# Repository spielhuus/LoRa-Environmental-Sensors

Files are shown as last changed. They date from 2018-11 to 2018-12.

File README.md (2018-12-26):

# LoRa Environmental Sensors 

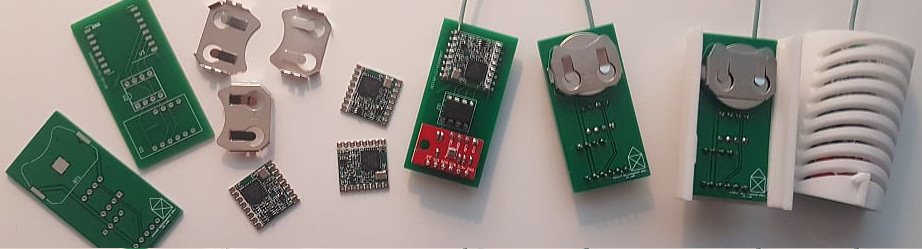
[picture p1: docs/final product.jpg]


Arduino based board for a Atmospheric Sensor BME280 LoRaWan Node. The LoRa Node measures barometric pressure, humidity, and temperature every 5 min. After the measurements, the ATtiny85 goes into sleep mode and is awakened by the watchdog timer. The RFM module sends the values to the TTN backend with Activation by Personalization (ABP) a fixed spreading factor and one of the four random channels. This project is based on the TinyLoRa-BME280 project [1].

## BOM

|Ref|Value|Description|
| --- | --- | --- |
|BT1| [3034](https://spielhuus.github.io/LoRa-Environmental-Sensors/3034.pdf) |Battery Cell Holder|3034 1x20mm](https://www.keyelco.com/product.cfm/product_id/798)| 
|BT1| CR2032 |Battery Cell CR2032 (210 – 230 mAh)| 
|U1| [BME280](https://spielhuus.github.io/LoRa-Environmental-Sensors/BST-BME280_DS001-10.pdf) | [SparkFun BME280](https://github.com/sparkfun/SparkFun_BME280_Breakout_Board)|
|U2| [ATtiny85-20SU](https://spielhuus.github.io/LoRa-Environmental-Sensors/atmel-2586-avr-8-bit-microcontroller-attiny25-attiny45-attiny85_datasheet.pdf) | Atmel 8-bit AVR Microcontroller|
|U3| [RFM95W-868S2](https://spielhuus.github.io/LoRa-Environmental-Sensors/RFM95_96_97_98W.pdf) | Low Power Long Range Transceiver Module |
| - | Wire | Wire for the antenna, 8.6 cm |

The ATmega microprocessor needs an arduino bootloader. To burn a bootloader to the blank chip see [2]

## Wiring

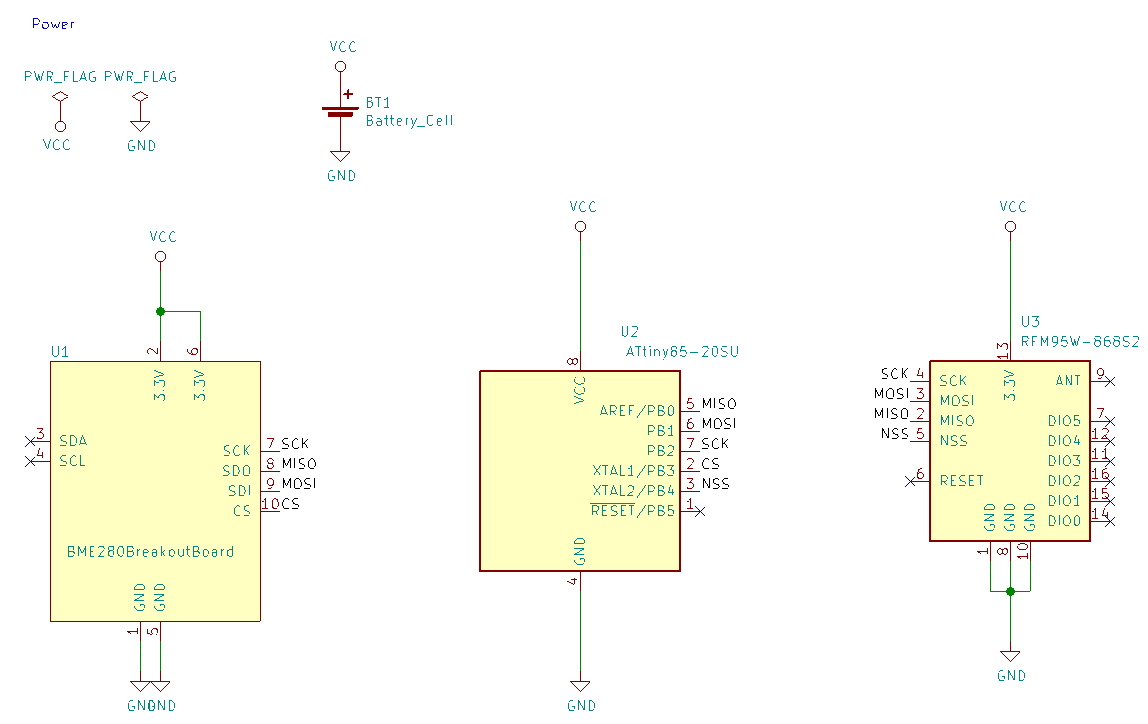
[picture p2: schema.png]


| ATtiny85 | RFM95 | BME280 |
| --- | ----- | --- |
| PB3 | | CS (Slave Select) |
| PB4 | NSS (Slave Select) | |
| PB2 | SCK | SCK |
| PB1(DO) | MOSI | SDI |
| PB0(DI) | MISO | SDO |

## Installation

The Arduino IDE has to be properly installed. 

Add the Libraries to you IDE:

- Install the Attiny Baord Manager
  - Under Preferences > Additional Boards Manager URLs: https://raw.githubusercontent.com/damellis/attiny/ide-1.6.x-boards-manager/package_damellis_attiny_index.json

  Multiple managers can be separated with a comma.

- Install TinyLoRa-BME280 v1.1
  - Download the ZIP archive from [TinyLoRa-BME280 v1.1](https://github.com/ClemensRiederer/TinyLoRa-BME280_v1.1)
  - Install the ZIP archive in the Arduino Library Manager

- Open Examples > TinyLoRa-BME280_v1.1-master > ATtiny_LoRa_BME280
  - Edit NwkSkey, AppSkey, DevAddr
  - Change the Spreading Factor in ATtinyLoRa.cpp
  - The Sleep time can be set with the SLEEP_TOTAL var.

- Burn the sketch to the Chip using an Arduino UNO [2]
  - Burn a bootloader first to set the fuses correctly

## Payload Format

The Payload is encoded as byte array.

| byte | content |
| ---- | --- |
| 0..1 | temperature (*100) |
| 2..3 | humidity (*100) |
| 4..8 | barometric pressure |

To decode the values add this code in the TTM Console as decoder under Paload Formats.

```
function Decoder(bytes, port) {
  temp = ((bytes[0]) << 8)
              + ((bytes[1]));
  hum = ((bytes[2]) << 8)
              + ((bytes[3]));
  pres = ((bytes[4]) << 24)
              + ((bytes[5]) << 16)
              + ((bytes[6]) << 8)
              + ((bytes[7]));

  return {
    pressure: ( pres / 100 ),
    temperature: ( temp / 100 ),
    humidity: ( hum / 100 )
  };
}
```

## Links

1. [TinyLoRa-BME280 v1.1](https://github.com/ClemensRiederer/TinyLoRa-BME280_v1.1)
2. [Programming ATtiny85 with Arduino Uno](https://www.hackster.io/arjun/programming-attiny85-with-arduino-uno-afb829)

## License

[License CC BY 4.0](http://creativecommons.org/licenses/by/4.0/) - Attribution 4.0 International

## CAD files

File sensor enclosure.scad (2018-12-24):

// Enclosure for the LoRA environmental sensor.

l=52;
w=27;
th=5;
h=12;

board_w=25;
board_l=50;
board_h=2;

lidText = "2";  // Text on lid    
lidTextSize = 20;   // Size of text on Lid
lidTextFont = "Droid Sans:style=Bold";  // Font for lid text

// the text
translate([0,-l/2+5,-th-w/2+1])
    rotate(0) linear_extrude(height = 3)
        mirror([1,0,0]) 
            text(lidText, font = lidTextFont, size = lidTextsize, valign = "center", halign = "center");

//the slider for the pcb
difference() {
    translate([-w/2,-l/2,-h/2+board_h-1]) cube([board_w+3,board_l,board_h+2] );
    translate([0,th/2,-h/2+3]) cube([board_w+1,board_l+2*th,board_h], center=true);
    translate([0,th/2,-h/2+3]) cube([board_w-2,board_l+2*th,board_h+2], center=true);
}


translate([-w/2-th/4,0,-h/2+3+th]) cube([th/2,l,th], center=true);
translate([+w/2+th/4,0,-h/2+3+th]) cube([th/2,l,th], center=true);

translate([0,0,0]) {
    difference() {
        rotate(a=[0,270,90]) cylinder(h=l,d=w+th,center=true,$fn=100);
        rotate(a=[0,270,90]) cylinder(h=l+th,d=w,center=true,$fn=100);
        translate([0,0,h]) cube([w*2,l,h*2], center=true);

        //vents
        translate([0, -10,-w]) rotate([120,0,0]) cube([w*2,l,2], center=true);
        translate([0, -5,-w]) rotate([120,0,0]) cube([w*2,l,2], center=true);
        translate([0, 0,-w]) rotate([120,0,0]) cube([w*2,l,2], center=true);
        translate([0, 5,-w]) rotate([120,0,0]) cube([w*2,l,2], center=true);
        translate([0, 10,-w]) rotate([120,0,0]) cube([w*2,l,2], center=true);
        translate([0, 15,-w]) rotate([120,0,0]) cube([w*2,l,2], center=true);
        translate([0, 20,-w]) rotate([120,0,0]) cube([w*2,l,2], center=true);
        translate([0, 25,-w]) rotate([120,0,0]) cube([w*2,l,2], center=true);
        translate([0, 30,-w]) rotate([120,0,0]) cube([w*2,l,2], center=true);
    }
}

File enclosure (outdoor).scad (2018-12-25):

// Which one would you like to see?
part = "both"; // [box:Box only, top: Top cover only, both: Box and top cover]

// Size of your printer's nozzle in mm
nozzle_size = 0.4;

// Number of walls the print should have
number_of_walls = 2; // [1:5]

// Tolerance (use 0.2 for FDM)
tolerance = 0.2; // [0.1:0.1:0.4]

// Outer x dimension in mm
x=52+2*number_of_walls*nozzle_size+2*3*nozzle_size;

// Outer y dimension in mm
y=27+2*number_of_walls*nozzle_size+2*3*nozzle_size;

// Outer z dimension in mm
z=13+2*number_of_walls*nozzle_size+2*3*nozzle_size;

// Radius for rounded corners in mm
radius=4; // [1:20]

lidText = "7";  // Text on lid    
lidTextSize = 10;   // Size of text on Lid
lidTextFont = "Droid Sans:style=Bold";  // Font for lid text

/* Hidden */
$fn=100;

wall_thickness=nozzle_size*number_of_walls;
hook_thickness = 3*nozzle_size;

top_cover_wall_thickness = hook_thickness + wall_thickness;

module bottom_box () {
    difference(){
        // Solid box
        linear_extrude(z-wall_thickness){
            minkowski(){
                square([x-radius*2,y-radius*2], center=true);
                circle(radius, center=true);
            }
        }
        
        // Hollow out
        translate([0,0,wall_thickness]) linear_extrude(z){
            minkowski(){
                square([x-radius*2-wall_thickness*2+wall_thickness*2,y-radius*2-wall_thickness*2+wall_thickness*2], center=true);
                circle(radius-wall_thickness);
            }
        }
        
            //hole for antenna and vents
        translate([-x/2+3, 7, 2+3]) rotate(a=[0,270,0]) cylinder(h=20, d=2, $fn=100);
        translate([+x/4, -0, 1]) rotate(a=[0,0,90]) cube(size = [2,20,10], center = true);
        translate([+x/4, -4, 1]) rotate(a=[0,0,90]) cube(size = [2,20,10], center = true);
        translate([+x/4, -8, 1]) rotate(a=[0,0,90]) cube(size = [2,20,10], center = true);
        translate([+x/4, +4, 1]) rotate(a=[0,0,90]) cube(size = [2,20,10], center = true);
        translate([+x/4, +8, 1]) rotate(a=[0,0,90]) cube(size = [2,20,10], center = true);

        // the text
        translate([-10,-0,-2-2/2+1])
            rotate(270) linear_extrude(height = 3)
                mirror([1,0,0]) 
        text(lidText, font = lidTextFont, size = lidTextSize, valign = "center", halign = "center");
    }

    left_hook(); // left hook
    rotate([180,180,0]) left_hook(); // right hook
    front_hook(); // front hook
    rotate([180,180,0]) front_hook(); // back hook
    // TODO: hooks on the other two sides
}

module left_hook () {
    
    translate([(x-2*wall_thickness)/2,-y/2+radius*2,z-wall_thickness]) rotate([0,90,90]) {
        difference(){
            linear_extrude(y-2*radius*2){
    polygon(points=[[0,0],[2*hook_thickness,0],[hook_thickness,hook_thickness]], center=true);
        }
             translate([hook_thickness, hook_thickness, 0]) rotate([45,0,0]) cube(2*hook_thickness, center=true);
             translate([hook_thickness, hook_thickness, y-2*radius*2]) rotate([45,0,0]) cube(2*hook_thickness, center=true);        
        }
    }
}
    

module front_hook () {
    translate([(-x+4*radius)/2,-y/2+wall_thickness,z-wall_thickness]) rotate([90,90,90]) {
        difference(){
        linear_extrude(x-2*radius*2){
    polygon(points=[[0,0],[2*hook_thickness,0],[hook_thickness,hook_thickness]], center=true);
    }
             translate([hook_thickness, hook_thickness, 0]) rotate([45,0,0]) cube(2*hook_thickness, center=true);
             translate([hook_thickness, hook_thickness, x-2*radius*2]) rotate([45,0,0]) cube(2*hook_thickness, center=true);
        }
    }
}


module right_grove () {
    translate([-tolerance/2+(x-2*wall_thickness)/2,-y/2+radius,wall_thickness+hook_thickness*2]) rotate([0,90,90]) linear_extrude(y-2*radius){
    polygon(points=[[0,0],[2*hook_thickness,0],[hook_thickness,hook_thickness]], center=true);
    }
}


module front_grove () {
    translate([(-x+2*radius)/2,-y/2+wall_thickness+tolerance/2,wall_thickness+hook_thickness*2]) rotate([90,90,90]) linear_extrude(x-2*radius){
    polygon(points=[[0,0],[2*hook_thickness,0],[hook_thickness,hook_thickness]], center=true);
    }
}

module top_cover () {

    // Top face
    linear_extrude(wall_thickness){
        minkowski(){
            square([x-radius*2,y-radius*2], center=true);
            circle(radius, center=true);
        }
    }
    
    difference(){
        // Wall of top cover
        linear_extrude(wall_thickness+hook_thickness*2){
            minkowski(){
                square([x-radius*2-wall_thickness*2-tolerance+wall_thickness*2,y-radius*2-wall_thickness*2-tolerance+wall_thickness*2], center=true);
                circle(radius-wall_thickness, center=true);
            }
        }
        
        // Hollow out
        // TODO: If radius is very small, still hollow out

        translate([0,0,wall_thickness]) linear_extrude(z){
            minkowski(){
                square([x-radius*2-wall_thickness*2-2*top_cover_wall_thickness-tolerance+wall_thickness*2+top_cover_wall_thickness*2,y-radius*2-wall_thickness*2-2*top_cover_wall_thickness-tolerance+wall_thickness*2+top_cover_wall_thickness*2], center=true);
            circle(radius-wall_thickness-top_cover_wall_thickness);
            }
        }
    right_grove();
    rotate([180,180,0]) right_grove();
    front_grove();
    rotate([180,180,0])  front_grove();
    }
  

}

// left_hook();
print_part();

module print_part() {
	if (part == "box") {
		bottom_box();
	} else if (part == "top") {
		top_cover();
	} else if (part == "both") {
		both();
	} else {
		both();
	}
}

module both() {
	translate([0,-(y/2+wall_thickness),0]) bottom_box();
    translate([0,+(y/2+wall_thickness),0]) top_cover();
}

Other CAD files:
enclosure (indoor).scad

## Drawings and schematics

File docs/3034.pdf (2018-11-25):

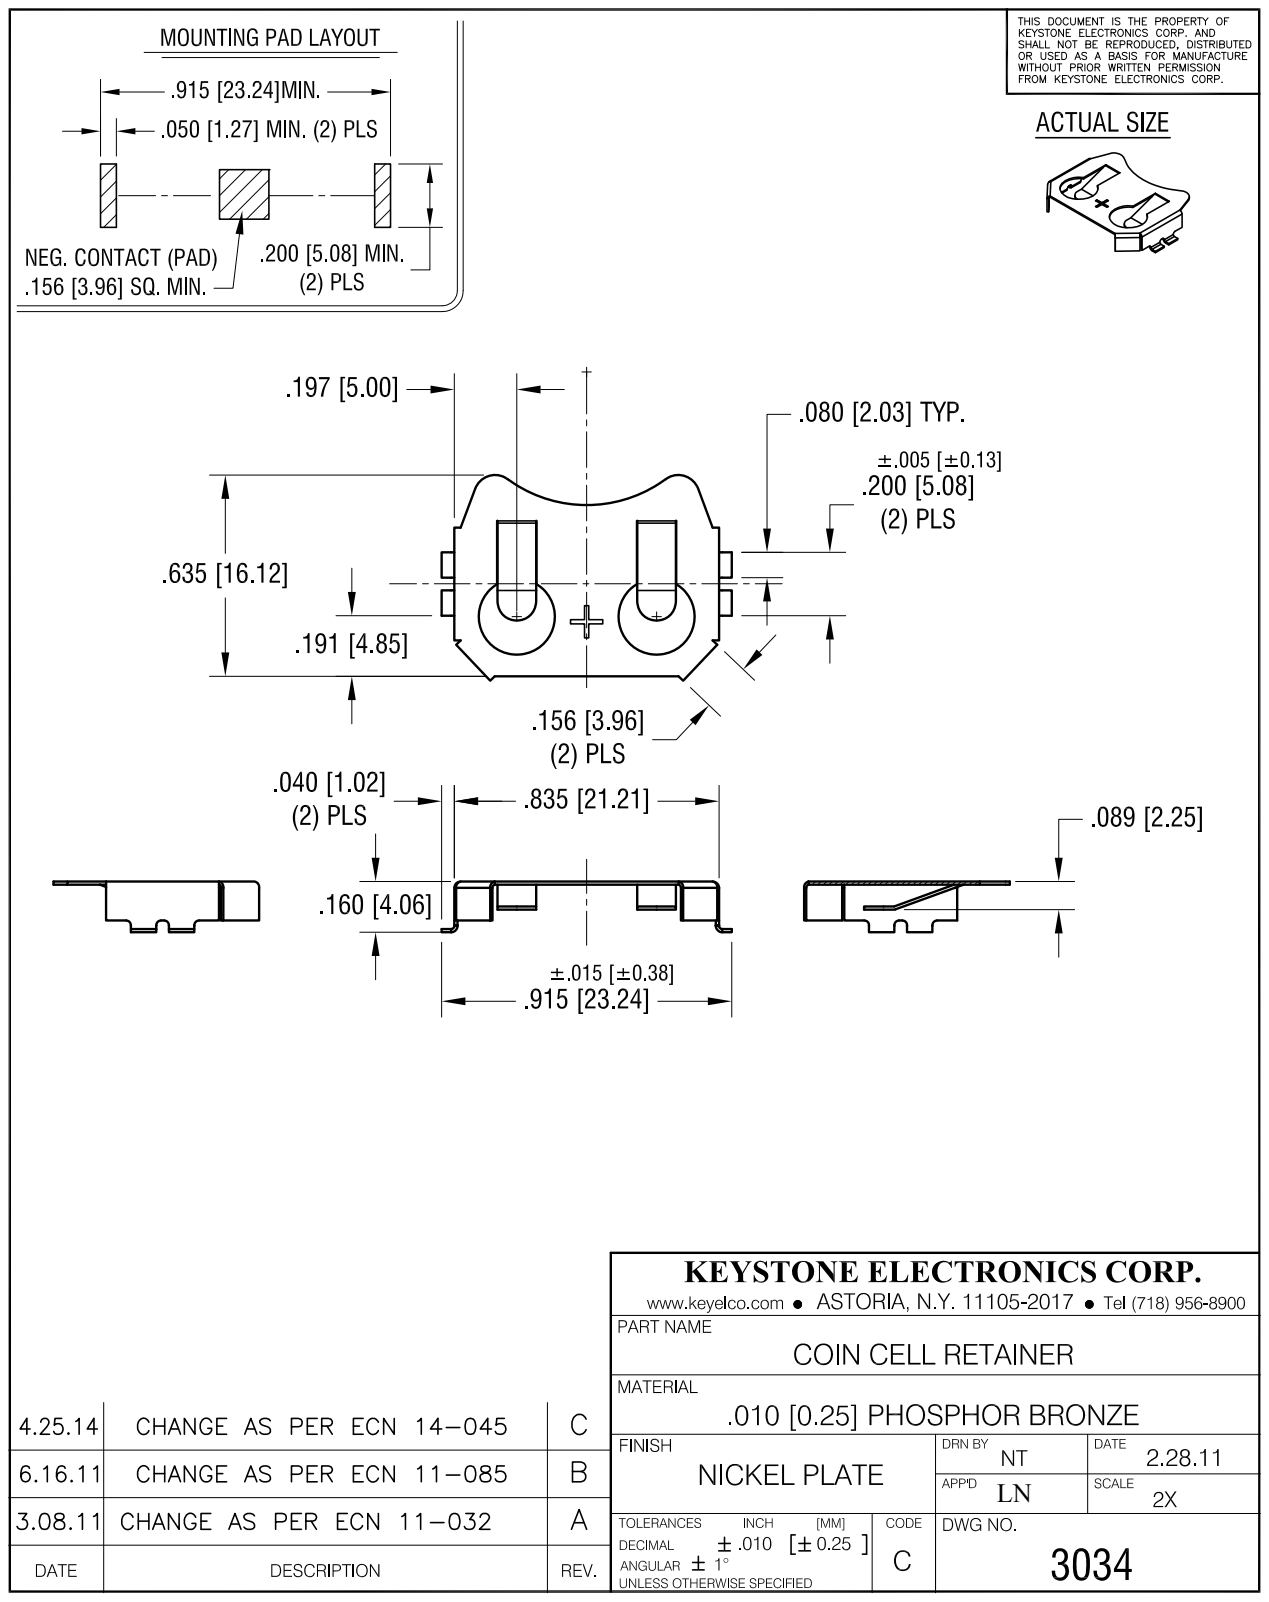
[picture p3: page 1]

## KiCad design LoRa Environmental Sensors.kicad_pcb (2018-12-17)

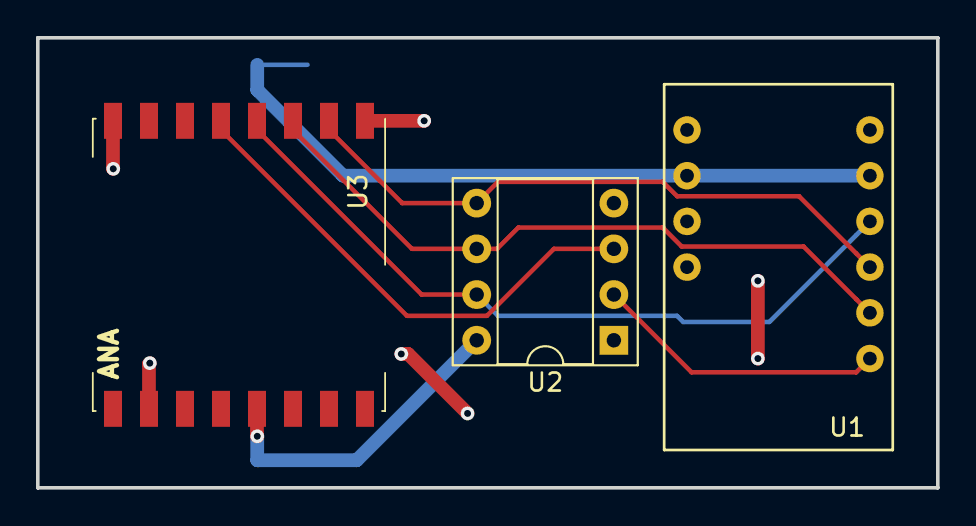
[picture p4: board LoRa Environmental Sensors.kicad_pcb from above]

Board: 2 copper layers, 50.0 x 25.0 mm, 4 parts (1 on the bottom side), 7 nets.

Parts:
BT1: Battery_Cell; BatteryHolder_Keystone_3034_1x20mm
U1: BME280BreakoutBoard; Sparkfun bme280
U2: ATtiny85-20SU; DIP-8_W7.62mm_Socket
U3: RFM95W-868S2; HOPERF_RFM9XW_SMD

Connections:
/CS: U1.10, U2.2
/MISO: U1.8, U2.5, U3.2
/MOSI: U1.9, U2.6, U3.3
/NSS: U2.3, U3.5
/SCK: U1.7, U2.7, U3.4
GND: BT1.2, U1.1, U1.5, U2.4, U3.1, U3.8, U3.10
VCC: BT1.1, U1.2, U1.6, U2.8, U3.13

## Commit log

2018-11-25 add gerber files
    [LoRa Environmental Sensors-B.Cu.gbl, LoRa Environmental Sensors-B.Mask.gbs, LoRa Environmental Sensors-B.SilkS.gbo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]
2018-11-25 update pcb
    [LoRa Environmental Sensors.kicad_pcb]
2018-11-25 update gerbers
    [LoRa Environmental Sensors-B.Cu.gbl, LoRa Environmental Sensors-B.Mask.gbs, LoRa Environmental Sensors-B.SilkS.gbo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]
2018-11-25 update gerber files
    [LoRa Environmental Sensors-B.Cu.gbl, LoRa Environmental Sensors-B.Mask.gbs, LoRa Environmental Sensors-B.SilkS.gbo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]
2018-12-17 Create Enclosure Main.scad
    [Enclosure Main.scad]
2018-12-17 add enclosure
    [Enclosure Main.scad, Enclosure Main.stl]
2018-12-18 update enclosure
    [Enclosure Main.scad, Enclosure Main.stl]
2018-12-23 update 3d model
    [Enclosure Main.scad, Enclosure Main.stl]
2018-12-24 add new enclosure
    [sensor enclosure.scad, sensor enclosure.stl]
2018-12-24 update sensor 02
    [sensor enclosure.scad, sensor enclosure.stl]
2018-12-25 add outdoor enclosure
    [Enclosure Main.scad, Enclosure Main.stl, enclosure (indoor).scad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]
2018-12-25 sensor 4
    [enclosure (indoor).scad, enclosure (indoor).stl]
2018-12-26 update final prodcut picture
    [enclosure (indoor).stl, enclosure (outdoor).stl]
